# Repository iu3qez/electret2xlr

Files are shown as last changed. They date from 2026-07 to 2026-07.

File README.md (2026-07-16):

# electret2xlr

Active adapter that powers an electret microphone from P48 phantom power and presents its signal to a balanced XLR input — no external supply. Built as pcb-as-code with the [`pcb`](https://github.com/diodeinc/pcb) toolchain (Zener language). Designed for a ham-radio shack, so **RF immunity is a first-class requirement**, not an afterthought.

The electronics live in an external **copper-foil enclosure** (Faraday shield) and connect to the sound card through a shielded cable ending in a **flying male XLR plug** (e.g. Neutrik NC3MX).

## How it works

Three stages (~15 passives/actives plus connectors):

1. **Supply (capacitance multiplier).** Phantom 48 V is tapped symmetrically from XLR pins 2/3. An 8.2 V zener (D1) sets a raw reference; R9 47 kΩ + C4 47 µF push the corner below 1 Hz to scrub the zener's avalanche noise; NPN follower Q1 (MMBT3904) buffers it into a clean **VPIP ≈ 7.5 V** rail. Capsule bias comes off VPIP through R10 6.8 kΩ.
2. **Audio (matched class-A followers).** Two PNP emitter followers (MMBT3906): **Q2** (hot) takes the capsule signal (AC-coupled via C2) and modulates the current drawn from pin 2 through R1 7.5 kΩ; **Q3** (cold) is identical but AC-grounded, drawing from pin 3 through R2 10 kΩ. Result: pseudo-balanced ~78 Ω source, ~3 mA/pin symmetric. CB2/CB3 emitter-bypass caps are **1 µF** (not 22 µF — a larger value pushes the HP knee below 1 Hz and defeats the intended ~30 Hz roll-off).
3. **Input.** Capsule solder pads (MIC1) and an optional 3.5 mm TRS jack (J2), preceded by a π anti-RF filter (CIN 220 pF + FB1 ferrite + RIN 100 Ω) — the mic cable is the main antenna, so this is the front line against HF detection on the capsule FET.

Extra RF defenses: CP2/CP3 (100 pF C0G, pin2/pin3→GND), CSH (1 nF, shell→GND), and a 4-layer board with internal ground planes in addition to the copper enclosure.

## Key figures (SPICE-verified)

From `docs/sim-results.md` (ngspice via `pcb sim`):

| Quantity | Simulated | Target |
|---|---|---|
| V(VPIP) | 7.49 V | 7.0–8.0 V |
| V(MICOUT) | 4.09 V | 3–5 V |
| Current per pin (P2 / P3) | 3.00 / 3.13 mA | 2.5–3.5 mA |
| P2 vs P3 imbalance | 4.4 % | < 10 % |
| Flatness 100 Hz–20 kHz | 0.44 dB | ±1 dB |
| Low −3 dB roll-off | ≈ 30.6 Hz | 20–60 Hz |

The differential output phase at 1 kHz is ≈ −179° (inverted vs the conventional sign) — a known trait shared with the reference design, left as a bench-verification item, not fixed here.

## Build

Prerequisites: **`pcb`** (Rust binary, not on PyPI) and **KiCad 10.x** (only needed for `pcb layout`).

```bash
curl -fsSL https://raw.githubusercontent.com/diodeinc/pcb/main/install.sh | bash
export PATH="$HOME/.local/bin:$PATH"        # pcbc 0.4.7 used here
git clone https://github.com/iu3qez/electret2xlr && cd electret2xlr
pcb build electret2xlr.zen                  # 32 components, no errors
pcb layout electret2xlr.zen                 # open/update layout in KiCad
```

Footprints and symbols are **vendored** (`footprints/`, `symbols/`), so a clean clone builds offline — **no `pcb auth login` or online registry needed**. KiCad 10.x install: official AppImage (no sudo), Flatpak `org.kicad.KiCad`, or a distro package with 10.x.

**Placement and routing are left to the user.** The imported `layout/layout.kicad_pcb` (4-layer, 1.6 mm, 50×40 mm outline) has components at netlist-import coordinates. DRC therefore reports the 51 unrouted nets plus a few overlap violations from `J1` auto-dropped onto the C4/Q2/J2 cluster — both clear once parts are placed.

Optional SPICE re-run (needs `ngspice`):

```bash
NGSPICE=/path/to/ngspice pcb sim electret2xlr.zen --config sim_mode=true --setup testbench/setup_dc_ac.cir -v
```

`sim_mode=true` drops the two capsule test points (no stdlib SPICE model); a normal `pcb build` keeps them as real pads.

## Wiring

- **J1 → flying XLR** (`footprints/J1_XLR3_WirePads.kicad_mod`, 3 THT pads): pin1 = GND/shield, pin2 = hot (P2), pin3 = cold (P3). Solder the shielded cable here; wire the other end to a male XLR plug (pin1 shield, pin2 +, pin3 −). Bond the copper enclosure to GND at pin 1.
- **Capsule** on MIC1 pads (2.54 mm pitch): signal/bias to one pad, GND to the other; observe the capsule's own polarity.
- **Jack J2** (optional, on the enclosure): tip = signal/bias, ring bridged to tip, sleeve = GND. Smartphone TRRS headsets need an external TRRS→TRS adapter.
- **SHELL pad:** the copper-foil contact (net `SHELL`, where CSH lands) is a hand-drawn copper feature tied to GND, not a netlist part — so `pcb build` emits an expected single-pin-net ERC warning for `SHELL`.

## Attribution & license

Topology inspired by [tphakala/p48-pip-adapter](https://github.com/tphakala/p48-pip-adapter). That project's CC BY-NC 4.0 covers its concrete design (layout, gerbers, docs), not the circuit topology — a widely published functional idea. This repo's Zener source, layout, and docs are written from scratch, so no license constraint is inherited; attribution here is a courtesy.

## Reference docs

- `docs/superpowers/specs/2026-07-15-electret2xlr-design.md` — full design spec
- `docs/sim-results.md` — SPICE verification (DC + AC)
- `docs/meccanica.md` — mechanical fit study (historical: in-connector mount, superseded by the external enclosure)
- `docs/bom.md` — bill of materials

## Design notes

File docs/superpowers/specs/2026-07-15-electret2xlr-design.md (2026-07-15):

# electret2xlr — Design

**Data:** 2026-07-15
**Stato:** approvato

## Scopo

Adattatore attivo che collega un microfono electret (capsula a 2 terminali saldata, oppure mic da headset/lavalier via jack 3.5mm TRS) a un ingresso XLR bilanciato di una scheda audio, alimentato esclusivamente dalla phantom P48 (48V standard, 6.8kΩ per ramo). Il circuito vive su un PCB in un guscio esterno di lamina di rame (schermo), collegato alla scheda audio con un cavetto schermato che termina in uno spinotto XLR maschio volante (NC3MX). *(Il progetto originale prevedeva il montaggio dentro il corpo dell'NC3MXX; abbandonato il 2026-07-16 per mancanza di spazio — vedi §PCB e meccanica.)*

Contesto d'uso: shack radioamatoriale con trasmettitore HF collegato (indirettamente) alla stessa scheda audio → **l'immunità RF è un requisito di progetto**, non un optional.

Filosofia: KISS ma pulita e funzionale. Descrizione hardware in pcb-as-code con il toolchain `pcb`/Zener di Diode Inc.

## Origine della topologia

Il circuito adotta la topologia del progetto [tphakala/p48-pip-adapter](https://github.com/tphakala/p48-pip-adapter). Nota licenza: la CC BY-NC 4.0 del progetto originale copre il *design concreto* (layout, gerber, documentazione), non la topologia circuitale, che è un'idea funzionale ampiamente pubblicata e non proteggibile. Poiché sorgente Zener, layout e documentazione vengono rifatti da zero, il nostro progetto non eredita alcun vincolo di licenza; l'attribuzione nel README è una cortesia, non un obbligo.

Motivazioni della scelta attiva (rispetto all'alternativa passiva impedance-balanced valutata e scartata):

1. **Rumore zener:** in una capsula a 2 terminali il nodo di bias è anche il nodo del segnale; in un design passivo il rumore di valanga dello zener finisce quasi direttamente nel segnale. Il moltiplicatore di capacità lo elimina (taglio RC < 1Hz).
2. **Impedenza d'uscita:** ~78Ω contro i ~kΩ del passivo → guida cavi lunghi senza perdite HF e con migliore immunità.
3. **Bias più alto:** ~7.5V contro 3–4V → più headroom per la capsula.
4. **RF:** la difesa non è "meno giunzioni" ma schermatura (PCB 4 strati con piani di massa interni + guscio XLR) più filtraggio esplicito.

## Circuito

Tre stadi funzionali (~15 componenti):

### Alimentazione (moltiplicatore di capacità)

- Prelievo simmetrico dai pin 2 e 3.
- Zener 8.2V (SOD-123) come riferimento grezzo.
- Filtro RC (R9 47kΩ + C4 47µF): corner sotto 1Hz, elimina il rumore di valanga dello zener.
- Emitter follower NPN Q1 (MMBT3904) → rail PIP ~7.5V pulito, bypass 10µF.
- Bias capsula: 6.8kΩ dal rail PIP al nodo segnale/tip.

### Stadio audio (follower in classe A, uscita impedance-balanced)

- Q2 (MMBT3906, PNP): base al segnale della capsula (accoppiata via C2 22µF), collettore a massa, emettitore alimentato da pin 2 attraverso R1 7.5kΩ → la corrente di segnale modula la corrente assorbita da pin 2 (audio sul ramo hot). CB2 1µF/50V X7R + stopper RB2 47Ω bypassano R1, abbassando l'impedenza d'uscita. (Valore rivisto da 22µF a 1µF in Task 5: con 22µF il taglio passa-alto cadeva a ~1Hz, contraddicendo il roll-off dolce sotto ~50Hz voluto; 1µF porta il ginocchio a ~30Hz — vedi `docs/sim-results.md`.)
- Q3 (MMBT3906): identico ma con base a massa in AC (C3), emettitore alimentato da pin 3 via R2 10kΩ, bypass CB3+RB3 gemello → ramo cold con impedenza identica al hot ma senza audio.
- Risultato: sorgente pseudo-bilanciata ~78Ω, piatta in banda audio (−0.56dB simulati nel progetto originale), roll-off deliberato sotto ~50Hz (bypass di emettitore).
- Assorbimento ~3mA per pin, simmetrico → compatibile con ingressi bilanciati elettronici e a trasformatore.
- CB2/CB3 siedono su ~23V DC → rating 50V obbligatorio (X7R).

### Ingresso

- **Jack 3.5mm TRS PCB-mount** sul retro: tip = segnale/bias, ring ponticellato al tip (compatibilità lavalier TRS), sleeve = GND. Le cuffiette TRRS da smartphone richiedono un adattatore esterno (scelta deliberata: circuito pulito).
- **Piazzole THT** in parallelo al jack per saldare direttamente una capsula a 2 terminali.
- **Anti-RF sull'ingresso** (il cavo headset è un'antenna): 100Ω serie + 220pF C0G direttamente sul connettore/piazzole, a protezione del FET interno della capsula (unico rivelatore AM non schermabile).

### Difesa RF aggiuntiva

- 100pF C0G da pin 2 → pin 1 e da pin 3 → pin 1, fisicamente adiacenti ai pin XLR.
- Ferrite (BLM18-class) in serie sul ramo segnale.
- 1nF tra pin 1 e piazzola guscio.
- Connettore Neutrik NC3MXX-EMC (contatto capacitivo shell→schermo) se disponibile; NC3MXX standard come ripiego.

## PCB e meccanica

> **Aggiornamento 2026-07-16:** il montaggio sandwich in-connettore descritto sotto
> è stato **abbandonato** (i 32 componenti non entrano nell'NC3MXX). Vedi il nuovo
> schema qui in cima; il testo sandwich è conservato come storico.

Schema attuale — **scheda in guscio esterno di lamina di rame** + cavetto schermato con spinotto XLR maschio volante (NC3MX):

- **4 strati** con piani di massa interni (schermatura, in aggiunta al guscio di rame).
- **Spessore 1.6mm standard** (non più 0.8mm: quello serviva solo al sandwich tra i pin).
- **Larghezza libera**; outline provvisorio 30×40mm, componenti su entrambi i lati. Da adattare al guscio.
- Il **guscio di lamina di rame** è la gabbia di Faraday e va **collegato a GND** (pin 1) in almeno un punto.
- `J1` = 3 piazzole THT a filo (`footprints/J1_XLR3_WirePads.kicad_mod`): pin1=GND/schermo, pin2=hot, pin3=cold, verso il cavetto.

Schema sandwich in-connettore — **STORICO/SUPERATO** (adottato dal p48-pip-adapter, poi scartato per mancanza di spazio):

- 4 strati, piani interni di massa (gabbia di Faraday attorno al front-end da µV).
- Spessore 0.8mm obbligatorio (1.6mm non entrava tra i pin).
- Larghezza 11.1mm; sandwich mount tra i tre pin dell'NC3MXX (interasse 7.62mm), pad 8mm su entrambe le facce, saldatura diretta pin→pad.
- Componenti solo sul lato top; 1206 per le resistenze di feed (dissipazione continua nel guscio chiuso).

## Componenti

- Tutti jellybean, **a stock LCSC** (preferire basic/preferred parts) o dallo stock personale, come da CLAUDE.md.
- **Vincolo footprint: nessun componente sotto lo 0603** (saldabilità a mano). Ammessi 0603/0805/1206, SOT-23, SOD-323.
- Transistor: MMBT3904 / MMBT3906 (SOT-23). Zener 8.2V SOD-123. Ceramici X7R 50V dove siedono su tensione elevata (accoppiamenti/bypass a ~23V DC).
- Gli opamp a stock (LM8261, LM358D) sono stati valutati e scartati: non reggono 48V (servirebbe comunque il regolatore), LM358 rumoroso e con crossover, e si perderebbe il bilanciamento DC naturale dei collettori sui pin.
- I valori sono nominali: possibile bench tuning dopo il primo prototipo.

## Toolchain e struttura repo

- `pcb` (Zener) installato con lo script ufficiale (`install.sh`, non da PyPI); KiCad 10.x per il layout.
- Skill ufficiali diodeinc (repo pcb, cartella `skills/`): `zener-language` per scrivere i .zen, `registry-search`/`librarian` per componenti a stock LCSC, `datasheet-reader` per il fit meccanico, `spice-sim` per la verifica elettrica.
- Struttura repo:
  - `pcb.toml` — workspace Zener
  - `electret2xlr.zen` — board top-level (eventuali moduli separati per power/audio se utile)
  - `README.md` — schema, teoria di funzionamento, BOM con codici LCSC, attribuzione al p48-pip-adapter
  - `CLAUDE.md` — preferenze di progetto (già presente)

## Verifica

1. `pcb build` pulito (netlist + ERC).
2. `spice-sim`: punto di lavoro DC (rail PIP ~7.5V, assorbimento ~3mA simmetrico per pin, tensioni sui BJT sane) e risposta in frequenza (piatta in banda, roll-off <50Hz).
3. `pcb layout` → DRC KiCad (placement/routing a cura dell'utente); board 4 strati, spessore 1.6mm, outline adattato al guscio esterno.
4. Fit meccanico: quote pad pin XLR contro datasheet Neutrik; fit-test fisico prima dell'ordine.
5. BOM: ogni parte con codice LCSC verificato a stock, o marcata "stock personale".

## Fuori scope

- Supporto TRRS/CTIA diretto (serve adattatore esterno).
- Phantom sotto 48V (P12/P24 non garantite).

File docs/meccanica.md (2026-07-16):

> **DECISIONE (2026-07-16) — montaggio in-connettore ABBANDONATO.** La prova di
> placement ha confermato che nell'NC3MXX (cavità non quotata sui datasheet) **non
> ci stanno tutti i 32 componenti**. Il progetto è passato a **scheda in guscio
> esterno di lamina di rame** (gabbia di Faraday) collegata alla scheda audio con un
> **cavetto schermato + spinotto XLR maschio volante** (NC3MX). Di conseguenza:
> board non più vincolata a 11.1mm (outline 50×40mm), **spessore 1.6mm**
> standard (non più 0.8mm), 4 strati mantenuti, `J1` = 3 piazzole THT a filo
> (`footprints/J1_XLR3_WirePads.kicad_mod`). L'analisi qui sotto sul fit dentro
> l'NC3MXX (Piano A/B, footprint sandwich) è **superata** e conservata solo come
> storico. Vedi README §"Fattore di forma: guscio esterno schermato".

# Verifica fit meccanico — electret2xlr dentro il Neutrik NC3MXX (Task 7) — STORICO/SUPERATO

Stato: **superato dalla decisione del 2026-07-16** (vedi riquadro sopra). Testo
originale conservato per storico.

## 1. Quote scheda e jack (dati di partenza, da Task 3/5/6)

- **PCB:** larghezza **11.1mm**, spessore **0.8mm**, 4 strati. Outline attuale in
  `layout/layout.kicad_pcb` (Edge.Cuts): rettangolo `(50,50)–(61.1,95)` →
  **11.1 × 45mm** (confermato leggendo il file; corrisponde al valore
  "provvisorio" citato nel commit di Task 6 `0528dec`).
- **Altezza assemblata:** 0.8mm PCB + massimo rilievo dei componenti lato top
  (~2.5mm, 1206/1210 e SOT-23) → **~3.3mm** di inviluppo verticale.
- **Sandwich XLR (J1):** i tre pin del NC3MXX (interasse bicchierini **7.62mm**)
  impegnano pad da **8mm** sul bordo scheda (pin1/2 fronte, pin3 retro), come da
  Task 6. Nessun connettore fisico: è il bordo PCB stesso a fare da lama nel
  sandwich.
- **Jack J2 — CUI/Same Sky SJ-3523-SMT-TR** (fonte: datasheet ufficiale
  "SJ-352X-SMT" rev 04/15/2025, letto in Task 3):
  - corpo (housing) **6.0mm × 14.5mm** (larghezza × lunghezza principale);
  - boccola/naso sporgente **2.5mm** oltre la faccia frontale del corpo →
    inviluppo utile fronte-retro **≈17mm** (coda terminali 2mm esclusa
    dall'inviluppo utile, sporge solo sul retro per la saldatura);
  - boccola: diametro esterno **Ø5.00mm**, foro interno **Ø3.60mm**;
  - altezza sopra PCB: **non quotata come cifra singola** nel disegno
    meccanico leggibile del datasheet; il valore desunto dalla tasca di
    imballo (packaging) è **6.1mm**, preso come stima conservativa **da
    confermare con lo STEP/3D ufficiale** (non scaricato/aperto finora).
  - footprint PCB consigliato dal datasheet: inviluppo **14.5 × 11.8mm**.
- **Precedente diretto — p48-pip-adapter** (stessa famiglia di connettore,
  stesso schema sandwich, verificato via GitHub
  `github.com/tphakala/p48-pip-adapter`, README): PCB **11.1 × 35.3 × 0.8mm**,
  *senza* jack (capsula saldata direttamente ai pad, PUI Audio AOM-5024). Note
  del progetto originale, citate testualmente:
  - "The thin edge has to fit into the gap between the three Neutrik pins; a
    standard 1.6mm board is far too thick" (conferma indipendente del vincolo
    0.8mm già adottato qui);
  - clearance dalla punta del pin al componente più vicino **≥5mm**, e per il
    pin3 la clearance del pad è scesa fino a **~0.5–0.7mm** (tolleranza molto
    stretta, tanto da richiedere pre-stagnatura e tecnica di saldatura
    dedicata);
  - il progetto include un **fit-test 3D-stampabile** prima di produrre, che è
    esattamente la pratica che raccomandiamo di ripetere qui (§6).

## 2. Quote ufficiali Neutrik NC3MXX reperite in questa sessione

Fonte primaria: datasheet ufficiale Neutrik, scaricato in questa sessione da
`https://www.neutrik.com/en/product/nc3mxx.pdf` (3 pagine, letto integralmente
pagina per pagina) e incrociato col catalogo generale
`https://www.neutrik.com/media/10098/download/01 NEUTRIK Section XLR
Connectors PG EN 202202-V23_opt.pdf` (sezione serie XX, riga "Cable O.D.
range").

Quote **effettivamente presenti in forma testuale/machine-readable**:

| Quota | Valore | Fonte |
|---|---|---|
| Cable O.D. accettato dal passacavo/ghiera posteriore | **3.5 – 8.0mm** | Datasheet NC3MXX pag. 2 ("Mechanical" → "Cable O.D."), confermato dal catalogo XLR generale (riga 500/571) |
| Wire size max | 2.5mm² / AWG 14 | Datasheet pag. 2 |
| Materiali/costruzione | shell zama nichelata, insert PA66, boot poliuretano | Datasheet pag. 3 |
| Rated voltage / dielectric strength | <50V / 1.5kVdc | Datasheet pag. 2 |

**Quote NON reperite in forma machine-readable in questa sessione** (dichiarato
esplicitamente, come richiesto dal brief — nessun numero è stato inventato):

- **Lunghezza/diametro utile della cavità interna per un PCB.** Il datasheet
  PDF ufficiale (2 varianti scaricate e ispezionate, più il catalogo XLR
  generale di 30 pagine passato a `pdftotext`) contiene solo tabelle
  elettriche/meccaniche generiche (vedi tabella sopra): **non contiene alcun
  disegno quotato in testo estraibile** — i disegni meccanici con quote sono
  presenti solo come immagini vettoriali nei file DXF/STEP ufficiali (link "3D
  Model"/"Drawing" sulla pagina prodotto Neutrik), che in questa sandbox non
  sono stati scaricabili/apribili (nessun visualizzatore CAD disponibile).
- **Diametro del foro/ghiera passacavo posteriore come cifra dimensionale
  diretta** (distinta dal range "Cable O.D." accettato). Il dato più vicino e
  ufficialmente quotato è il **Cable O.D. 3.5–8.0mm** sopra: è la specifica
  con cui il progettista Neutrik garantisce che il passacavo/boot/chuck a
  serraggio accetti cavi in quel range di diametro esterno — un proxy
  ragionevole ma non identico al "diametro del foro nudo".

Non ho inventato cifre di lunghezza cavità: dove serviva un numero e non era
disponibile, ho usato il **precedente reale p48-pip-adapter** (stesso
connettore, board 35.3mm fisicamente verificata) come riferimento empirico —
vedi §3.

## 3. Confronto fit

### 3.1 Larghezza e spessore assemblato — OK

- 11.1mm di larghezza scheda: **ampiamente sotto** qualunque lettura plausibile
  del diametro interno utile di uno shell XLR di questa classe (il corpo
  esterno stesso è nell'ordine di ~24mm di diametro per connettori cable-mount
  di questa famiglia — dato di conoscenza generale di settore, non citato da
  una fonte machine-readable Neutrik in questa sessione, quindi trattato come
  indicativo). Il precedente p48-pip-adapter usa la stessa larghezza 11.1mm
  nello stesso connettore e **è un prodotto reale, con fit verificato
  fisicamente dall'autore**: la larghezza non è un problema.
- Spessore assemblato ~3.3mm (0.8 PCB + ~2.5 componenti): stesso discorso, il
  precedente ha componenti equivalenti (SOT-23, 1206/1210) nello stesso guscio.
  **Nessun rischio noto.**

### 3.2 Lunghezza — punto critico, non confermabile a tavolino

Il precedente p48-pip-adapter (stesso connettore, nessun jack) ha impegnato
**35.3mm** di lunghezza per: zona sandwich pin XLR + tutto il circuito attivo
(BJT, zener, capacità, resistenze — un set di componenti molto simile al
nostro), lasciando solo **~5mm** di clearance dalla punta pin al componente più
vicino, e clearance ancora più risicata (~0.5–0.7mm) sul pad del pin3. Questo è
un'indicazione forte che **35mm circa è già vicino al limite pratico** di
lunghezza utilizzabile in questo connettore per un PCB analogo, verificato
empiricamente da chi ha stampato un fit-test 3D reale.

Il nostro circuito (`electret2xlr.zen`) replica lo stesso set di componenti del
precedente **più**:
- J2 (jack TRS SJ-3523-SMT-TR): inviluppo utile **~17mm** fronte-retro (14.5mm
  corpo + 2.5mm boccola sporgente);
- MIC1 (piazzole capsula, in parallelo al jack): ingombro trascurabile (2 THT
  pad Ø1mm passo 2.54mm).

Se il jack viene semplicemente accodato al layout del precedente senza
sovrapposizioni, la lunghezza necessaria sale a grandezza **35.3 + ~14.5 ≈
50mm** (il corpo del jack, non la sola boccola: la boccola dei 2.5mm sporge
*oltre* il bordo scheda dentro il passacavo, quindi non consuma ulteriore
lunghezza di PCB). L'outline attuale in `layout.kicad_pcb` è **45mm**, quindi
**circa 5mm più corto** di questa stima "somma diretta" — ma il vero margine
dipende dal placement effettivo (Task 6 ha volutamente lasciato
placement/routing all'utente: i footprint nel file sono ancora alle
coordinate di import del netlist, non posizionati sul board reale), quindi
45mm potrebbe bastare se c'è sovrapposizione/ottimizzazione nel piazzamento, o
potrebbe essere già insufficiente.

**Non è possibile risolvere questo punto solo da datasheet**: manca la quota
Neutrik della cavità interna utile (§2), e il precedente stesso mostra che il
margine reale in questo connettore è ridotto anche senza jack. Serve un
fit-test fisico (§6) prima di congelare la lunghezza.

**Raccomandazione lunghezza finale:** portare l'outline a **50mm** (rispetto
ai 45mm attuali) come target di lavoro per il placement in Task 6/KiCad, per
dare margine al jack pieno, **ma trattare 50mm come "da verificare fisicamente
prima di ordinare"**, non come quota garantita — vedi Piano B sotto se il
fit-test dimostra che lo shell non ospita 50mm.

### 3.3 Boccola jack (Ø5.00mm) vs passacavo/ghiera posteriore NC3MXX

- Il datasheet Neutrik quota il **Cable O.D. accettato dal passacavo/chuck a
  **3.5 – 8.0mm**. La boccola del jack SJ-3523-SMT-TR ha diametro esterno
  **Ø5.00mm**, quindi **rientra numericamente nel range dichiarato** per il
  passaggio dietro la ghiera/boot.
- Attenzione: quel range è pensato per un **cavo rotondo flessibile** stretto
  dal chuck a serraggio, non per un boss plastico rigido di forma leggermente
  diversa (il naso del jack è cilindrico ma con un piccolo gradino/flangia).
  Un Ø5mm rigido dovrebbe passare, ma la tenuta/serraggio del chuck non è
  garantita identica a quella su un cavo — **da verificare fisicamente**, non
  solo per numero.
- Nessuna necessità di forare il bushing standard: 5.00mm è già dentro il
  range 3.5–8.0mm, quindi **non serve sostituire/allargare il passacavo** per
  questa parte — il punto aperto resta solo la lunghezza (§3.2), non il
  diametro.

## 4. Riepilogo tabellare fit

| Verifica | Esito | Confidenza |
|---|---|---|
| Larghezza 11.1mm nella cavità | OK | Alta (precedente reale verificato) |
| Spessore assemblato ~3.3mm | OK | Alta (precedente reale verificato) |
| Lunghezza 45mm attuale (senza jack ottimizzato) | **Dubbio/probabilmente corto** | Bassa — nessuna quota Neutrik di cavità disponibile |
| Lunghezza 50mm raccomandata (con jack pieno) | Da verificare fisicamente | Bassa, stessa ragione |
| Boccola jack Ø5.00mm nel passacavo (range dichiarato 3.5–8.0mm) | Numericamente compatibile | Media (dato ufficiale Neutrik, ma per cavo non per boss rigido) |

## 5. Decisione sul montaggio del jack — DA CONFERMARE CON L'UTENTE

Non è possibile, sulla sola base dei datasheet, garantire che l'inviluppo
completo del jack J2 (≈17mm utili + il resto del circuito, board totale
~50mm) entri nella cavità interna del NC3MXX: la quota di cavità non è
pubblicata da Neutrik in forma machine-readable, e il precedente reale
(p48-pip-adapter) suggerisce che il margine disponibile in questo connettore è
già stretto **senza** alcun jack (35.3mm quasi al limite). Questo è un
genuino bivio, coerente con quanto la spec di progetto aveva già segnalato
come "rischio aperto":

**Piano A — jack J2 sul bordo posteriore della scheda (schema attuale)**
- Pro: mic 3.5mm TRS collegabile direttamente, nessun cavo volante, coerente
  col resto del progetto già autorato (`electret2xlr.zen`, footprint
  `Jack_3.5mm_CUI_SJ-3523-SMT_Horizontal` già presente).
- Contro: richiede board ~50mm (vs 35.3mm del precedente verificato),
  boccola Ø5mm da far sporgere nel passacavo esistente (numericamente
  compatibile ma non verificato fisicamente), **rischio concreto di non
  entrare nello shell** senza conferma da fit-test.

**Piano B — capsula su cavetto flying-lead attraverso il pressacavo standard
(piano B già previsto nella spec)**
- Il jack J2 esce dal PCB; la capsula/mic esterno si collega via un breve
  spezzone di cavo che esce dal pressacavo/boot standard del NC3MXX (lo
  stesso percorso già usato per il cavo microfonico in un connettore XLR
  cable-mount "normale").
- Pro: la board torna dimensionalmente al precedente **verificato fisicamente**
  (~35.3mm, stesso schema pin-sandwich, stesso ingombro dei componenti):
  **rischio di fit sostanzialmente azzerato**, perché è lo stesso schema già
  collaudato dal progetto sorgente.
- Contro: si perde la comodità "spina 3.5mm diretta nel corpo XLR"; l'utente
  deve saldare/assemblare un piccolo pigtail con jack esterno o terminazione
  a piacere; JJ2 (footprint/Component già scritto in `electret2xlr.zen`)
  andrebbe rimosso o reso opzionale/DNP e sostituito da un'uscita su cavetto.

**Raccomandazione:** dato che il precedente reale mostra margini già stretti
senza jack, e che non esiste una quota Neutrik ufficiale che confermi lo
spazio per un jack intero, **il Piano B è l'opzione a rischio meccanico più
basso**. Il Piano A resta preferibile se il fit-test fisico (§6) lo conferma,
perché offre più comodità d'uso. **Questa scelta va confermata dall'utente**
prima di congelare Task 6 (placement/routing) in via definitiva — segnalato
come DONE_WITH_CONCERNS in uscita da questo task.

## 6. Fit-test fisico raccomandato (prima di ordinare)

Indipendentemente dal piano scelto, **non ordinare PCB/connettori prima di
un test fisico**:

1. **Sagoma cartoncino 11.1 × L mm** (L = 45mm attuale, 50mm raccomandato per
   Piano A, o 35.3mm per Piano B), tagliata a spessore reale se possibile
   (impilare 2 strati di cartoncino ≈0.8mm), inserita a mano nello shell
   NC3MXX aperto (senza il retro/boot montato) per verificare visivamente lo
   spazio libero fino al boot/pressacavo.
2. In alternativa, più affidabile: **ordinare solo il PCB nudo** (senza
   componenti) nella lunghezza scelta e verificarne l'inserimento reale nel
   connettore comprato a parte, prima di ordinare l'intera BOM.
3. Se si sceglie Piano A, verificare *anche* che la boccola del jack (o un
   cilindretto di prova Ø5mm × ~5mm) passi effettivamente attraverso il
   pressacavo/boot montato, non solo attraverso lo shell aperto.
4. Ripetere l'esercizio del progetto originale p48-pip-adapter: un modello
   3D-stampabile del solo ingombro scheda+jack, infilato nello shell reale,
   resta il modo più economico per chiudere questo rischio senza attendere
   una fornitura PCB.

## 7. Incertezze aperte (riepilogo)

- **Quota ufficiale Neutrik della lunghezza/cavità interna utile**: non
  reperita in forma machine-readable in questa sessione (datasheet PDF e
  catalogo XLR generale ispezionati per intero, nessun disegno quotato in
  testo estraibile; i file DXF/STEP ufficiali non sono stati aperti, nessun
  visualizzatore CAD disponibile in sandbox). Uso di un precedente reale
  (p48-pip-adapter, 35.3mm) come miglior proxy disponibile, esplicitamente
  segnalato come tale.
- **Diametro effettivo del foro/ghiera nuda** (a differenza del range
  "Cable O.D." 3.5–8.0mm accettato dal chuck): non quotato separatamente da
  Neutrik in forma testuale.
- **Altezza reale del jack SJ-3523-SMT-TR sopra il PCB**: stimata a 6.1mm da
  una quota di imballo (packaging), non da un disegno meccanico dedicato —
  ereditata da Task 3, non rivalutabile senza lo STEP ufficiale.
- **Placement reale dei componenti**: Task 6 ha lasciato piazzamento e
  routing all'utente (i footprint sono ancora alle coordinate di import del
  netlist in `layout.kicad_pcb`, fuori dall'outline 11.1×45mm); la stima di
  lunghezza in questo documento (§3.2) è quindi basata su ingombri sommati,
  non su un placement verificato in KiCad.

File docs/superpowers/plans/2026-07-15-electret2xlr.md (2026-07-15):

# electret2xlr Implementation Plan

> **For agentic workers:** REQUIRED SUB-SKILL: Use superpowers:subagent-driven-development (recommended) or superpowers:executing-plans to implement this plan task-by-task. Steps use checkbox (`- [ ]`) syntax for tracking.

**Goal:** PCB (pcb-as-code Zener) di un adattatore attivo electret → XLR alimentato da phantom P48, montato dentro un connettore Neutrik NC3MXX, con ingresso jack TRS 3.5mm + piazzole capsula e hardening RF.

**Architecture:** Topologia p48-pip-adapter: moltiplicatore di capacità (zener 8.2V + RC <1Hz + follower NPN) → rail PIP ~7.5V; due follower PNP gemelli (hot con segnale su pin 2, cold a base AC-grounded su pin 3) → uscita impedance-balanced ~78Ω con assorbimento simmetrico ~3mA/pin. Aggiunte nostre: jack TRS + piazzole capsula con filtro π anti-RF in ingresso, 100pF sui pin XLR. PCB 4 strati 0.8mm, 11.1mm di larghezza, sandwich-mount tra i pin dell'XLR.

**Tech Stack:** `pcb` CLI (Zener/Starlark) di Diode Inc + KiCad 10.x + skill diodeinc (`zener-language`, `registry-search`, `librarian`, `datasheet-reader`, `spice-sim`) + ngspice per la simulazione.

**Spec di riferimento:** `docs/superpowers/specs/2026-07-15-electret2xlr-design.md` (approvata). Netlist di riferimento: `netlist.py` del repo https://github.com/tphakala/p48-pip-adapter (da consultare in lettura; NON copiarne layout/file: CC BY-NC).

## Global Constraints

- **Footprint minimo 0603** — mai componenti più piccoli; ammessi 0603/0805/1206/1210, SOT-23, SOD-323/SOD-123.
- **Componenti**: per questo progetto (passivi + transistor jellybean, tutte parti non critiche) il vincolo è il **footprint corretto**, non lo stock. Usare `registry-search` di diode per avere parti con footprint pronti per il `.zen`. La verifica di stock LCSC in tempo reale non è richiesta oggi (in futuro: DB jlcparts).
- **PCB: 4 strati, spessore 0.8mm (non negoziabile), larghezza 11.1mm**, strati interni = piani GND pieni via-stitched.
- **Alimentazione: solo phantom P48** (48V, 6.8kΩ/ramo); assorbimento simmetrico sui pin 2 e 3.
- **CB2/CB3 = 1µF X7R ≥50V** (siedono su ~23V DC; valore ratificato in Task 5 — 22µF metteva il taglio a ~1Hz contro il roll-off ~30-50Hz voluto). CP2/CP3 (100pF sui pin XLR) rating ≥100V C0G (siedono su 48V).
- Commit frequenti, messaggi in italiano che spiegano il perché, **niente riga Co-Authored-By**.
- Il "test" di ogni modifica al sorgente è `pcb build` pulito; per il layout è la DRC KiCad a zero errori.

---

### Task 1: Toolchain e skill diodeinc

**Files:**
- Create: `.claude/skills/zener-language/`, `.claude/skills/registry-search/`, `.claude/skills/librarian/`, `.claude/skills/datasheet-reader/`, `.claude/skills/spice-sim/` (copiati dal repo diodeinc/pcb)

**Interfaces:**
- Produces: comando `pcb` funzionante nel PATH; `kicad-cli` 10.x disponibile; skill consultabili in `.claude/skills/` per tutti i task successivi.

- [ ] **Step 1: Installa il CLI `pcb`** (non è su PyPI — verificato: è un binario Rust)

```bash
curl -fsSL https://raw.githubusercontent.com/diodeinc/pcb/main/install.sh | bash
export PATH="$HOME/.local/bin:$PATH"
pcb --version
```

Expected: versione stampata senza errori (es. `pcb x.y.z`).

- [ ] **Step 2: Verifica/installa KiCad 10.x** (richiesto da `pcb layout`)

```bash
kicad-cli version
```

Expected: `10.x`. Se assente o più vecchio: installare (Debian/Ubuntu: `sudo apt install kicad` se il repo ha la 10.x, altrimenti flatpak `flatpak install org.kicad.KiCad`). Se serve intervento dell'utente (sudo/password), fermarsi e chiederlo.

- [ ] **Step 3: Installa le skill diodeinc nel progetto**

```bash
git clone --depth 1 https://github.com/diodeinc/pcb /tmp/diode-pcb
mkdir -p .claude/skills
cp -r /tmp/diode-pcb/skills/* .claude/skills/
ls .claude/skills
```

Expected: `datasheet-reader  librarian  registry-search  spice-sim  zener-language`.

- [ ] **Step 4: Leggi la skill del linguaggio** — leggere per intero `.claude/skills/zener-language/SKILL.md` (e i file collegati). Le firme API usate nei task successivi (Module, Component, Net, Board, generics) vanno verificate contro questa skill e `pcb doc --package @stdlib`; in caso di divergenza fa fede la skill, non questo piano.

- [ ] **Step 5: Commit**

```bash
git add .claude/skills
git commit -m "Installa le skill diodeinc per il toolchain pcb/Zener"
```

---

### Task 2: Workspace Zener minimale

**Files:**
- Create: `pcb.toml`
- Create: `electret2xlr.zen` (stub di board vuota)

**Interfaces:**
- Produces: workspace che `pcb build` valida; `electret2xlr.zen` è il top-level che il Task 4 riempirà.

- [ ] **Step 1: Prova lo scaffolding ufficiale**

```bash
pcb new board electret2xlr github.com/sfabris/electret2xlr
```

Se il comando vuole creare una directory nuova invece di popolare il repo corrente, spostare i file generati nella root del repo. Se il comando non esiste in questa versione, creare i file a mano (Step 2).

- [ ] **Step 2 (fallback manuale): crea `pcb.toml`**

```toml
[workspace]
repository = "github.com/sfabris/electret2xlr"
pcb-version = "0.4"

[board]
name = "electret2xlr"
path = "electret2xlr.zen"
description = "Adattatore attivo electret -> XLR bilanciato alimentato da phantom P48, montato dentro un Neutrik NC3MXX."
```

e `electret2xlr.zen` stub (adattare la firma di `Board` a quanto dice la skill zener-language):

```zen
Board(name="electret2xlr", layout_path="layout/electret2xlr", layers=4)
```

- [ ] **Step 3: Valida**

```bash
pcb sync && pcb build electret2xlr.zen
```

Expected: build senza errori.

- [ ] **Step 4: Commit**

```bash
git add pcb.toml electret2xlr.zen
git commit -m "Scaffolding workspace Zener con board 4 strati vuota"
```

---

### Task 3: Selezione componenti a stock LCSC

**Files:**
- Create: `docs/bom-draft.md`

**Interfaces:**
- Produces: tabella con, per ogni ref, **MPN + package + footprint (dal registry diode) + simbolo/parte da usare nel `.zen`**; il Task 4 usa questi identificativi nei `Component(...)` / generics. Il codice LCSC è opzionale (annotarlo se il registry lo espone, ma non è un requisito).

Usare le skill `registry-search` e `librarian` di diode: l'obiettivo è ottenere per ogni posizione una parte con **footprint corretto** già utilizzabile nel `.zen`. Lo stock LCSC NON è un criterio di accettazione per questo progetto (parti tutte non critiche). Requisiti per posizione (valori dalla spec; candidati indicati dove noti):

| Ref | Parte | Requisiti | Candidato |
|-----|---|---|---|
| Q1 | MMBT3904 | NPN SOT-23 | LCSC C20526 (basic) |
| Q2, Q3 | MMBT3906 | PNP SOT-23 | LCSC C8492 |
| D1 | Zener 8.2V | SOD-123/SOD-323, ≥300mW | BZT52C8V2 |
| C1, C2, C3 | 22µF | X5R/X7R ≥16V, 1206/1210 | — |
| CB2, CB3 | 1µF (ratificato in Task 5) | **X7R ≥50V**, 1206/1210 | — |
| C4 | 47µF | ≥16V, ≤1210 | — |
| C5 | 10µF | ≥16V, 0805 | — |
| R1 | 7.5kΩ | **1206** (67mW continui) | — |
| R2 | 10kΩ | **1206** (50mW continui) | — |
| R3, R4, R6, R7 | 100kΩ | 0603 | — |
| R8 | 1kΩ | 0603 | — |
| R9 | 47kΩ | 0603 | — |
| R10 | 6.8kΩ | 0603 | — |
| RB2, RB3 | 47Ω | 0603 | — |
| RIN | 100Ω | 0603 | — |
| FB1 | Ferrite | 600Ω@100MHz, 0603, ≥200mA | BLM18AG601SN1 o equiv. LCSC |
| CIN | 220pF | C0G 0603 | — |
| CP2, CP3 | 100pF | **C0G ≥100V** 0603 | — |
| CSH | 1nF | C0G ≥100V 0603, **DNP** se si usa NC3MXX-EMC | — |
| J2 | Jack 3.5mm TRS | PCB-mount, corpo ≤11mm di larghezza, boccola compatibile con foro ghiera XLR | PJ-3133 / SJ-3523 / PJ-392: scegliere col datasheet |
| J1 | XLR (pad) | nessun componente: 3 pad sandwich definiti nel layout | — |
| MIC1 | Piazzole capsula | 2 pad THT Ø1mm passo 2.54mm | — |

- [ ] **Step 1:** per ogni riga, cercare con `registry-search` una parte diode con il footprint corretto; annotare MPN, package, footprint e l'identificativo da usare nel `.zen` (Module/Symbol) in `docs/bom-draft.md`. Codice LCSC solo se il registry lo espone (colonna opzionale).
- [ ] **Step 2:** per J2 individuare un jack 3.5mm TRS PCB-mount adatto e, se il datasheet è reperibile (`datasheet-reader` o web), annotare le dimensioni del corpo e della boccola (servono ai Task 6-7). Se non trovi un jack nel registry, annota comunque un MPN reale plausibile con le sue quote.
- [ ] **Step 3:** se per una posizione il registry non ha il footprint richiesto, annotare l'alternativa (footprint equivalente ≥0603) e proseguire; segnalare nel report solo se serve cambiare un *valore* del circuito (in quel caso fermarsi).
- [ ] **Step 4: Commit**

```bash
git add docs/bom-draft.md
git commit -m "BOM preliminare con componenti verificati a stock LCSC"
```

---

### Task 4: Netlist Zener completa

**Files:**
- Modify: `electret2xlr.zen`

**Interfaces:**
- Consumes: MPN/LCSC da `docs/bom-draft.md`; sintassi verificata dalla skill `zener-language`.
- Produces: board completa che passa `pcb build`; nomi di net stabili usati da sim e layout: `GND, P2, P3, VPIP, VREF, Q1B, MICIN, MICF, MICOUT, Q2B, Q2E, Q3B, Q3E, NB2, NB3, SHELL`.

Netlist da implementare (riferimento p48 + aggiunte RF; i pin BJT seguono la piedinatura SOT-23 MMBT390x: 1=B, 2=E, 3=C):

| Net | Connessioni | Funzione |
|-----|---|---|
| GND | J1-1, MIC1-2, J2-SLEEVE, D1-A, C4-2, C5-2, C1-2, C3-2, R4-2, R7-2, Q2-C, Q3-C, CIN-2, CP2-2, CP3-2, CSH-2 | massa |
| P2 | J1-2, R1-1, RB2-2, CP2-1 | XLR pin 2 (hot) |
| P3 | J1-3, R9-1, Q1-C, R2-1, RB3-2, CP3-1 | XLR pin 3 (cold + alimentazione regolatore) |
| VPIP | Q1-E, C5-1, C1-1, R10-1, R3-1, R6-1 | rail PIP ~7.5V |
| VREF | R9-2, D1-1, C4-1, R8-1 | riferimento zener filtrato |
| Q1B | R8-2, Q1-B | base regolatore |
| MICIN | J2-TIP, J2-RING (ponticello), MIC1-1, CIN-1, FB1-1 | nodo capsula/jack, con C anti-RF |
| MICF | FB1-2, RIN-1 | dopo la ferrite |
| MICOUT | RIN-2, R10-2, C2-1 | bias capsula + prelievo segnale |
| Q2B | R3-2, R4-1, C2-2, Q2-B | base hot |
| Q2E | R1-2, Q2-E, CB2-1 | emettitore hot |
| Q3B | R6-2, R7-1, C3-1, Q3-B | base cold (AC a massa) |
| Q3E | R2-2, Q3-E, CB3-1 | emettitore cold |
| NB2 | CB2-2, RB2-1 | bypass hot |
| NB3 | CB3-2, RB3-1 | bypass cold |
| SHELL | pad guscio, CSH-1 | schermo (CSH DNP con NC3MXX-EMC) |

Nota zener D1: il catodo va su VREF (nodo positivo, clampa a +8.2V), l'anodo a GND. Verificare la convenzione dei pin del simbolo scelto.

- [ ] **Step 1: scrivi `electret2xlr.zen`.** Struttura di riferimento (adattare le firme alla skill; i `Part`/simboli vengono dalla BOM del Task 3):

```zen
Resistor = Module("@stdlib/generics/Resistor.zen")
Capacitor = Module("@stdlib/generics/Capacitor.zen")
FerriteBead = Module("@stdlib/generics/FerriteBead.zen")  # se non esiste nel stdlib: Component con MPN LCSC

GND = Net("GND")
P2 = Net("P2")
P3 = Net("P3")
VPIP = Net("VPIP")
VREF = Net("VREF")
Q1B = Net("Q1B")
MICIN = Net("MICIN")
MICF = Net("MICF")
MICOUT = Net("MICOUT")
Q2B = Net("Q2B")
Q2E = Net("Q2E")
Q3B = Net("Q3B")
Q3E = Net("Q3E")
NB2 = Net("NB2")
NB3 = Net("NB3")
SHELL = Net("SHELL")

# --- alimentazione (cap multiplier) ---
Resistor(name="R9", value="47kohm", package="0603", P1=P3, P2=VREF)
Component(name="D1", symbol=Symbol(...zener BZT52C8V2...), pins={"K": VREF, "A": GND})
Capacitor(name="C4", value="47uF", package="1210", P1=VREF, P2=GND)
Resistor(name="R8", value="1kohm", package="0603", P1=VREF, P2=Q1B)
Component(name="Q1", symbol=Symbol(...MMBT3904...), pins={"B": Q1B, "E": VPIP, "C": P3})
Capacitor(name="C5", value="10uF", package="0805", P1=VPIP, P2=GND)
Capacitor(name="C1", value="22uF", package="1206", P1=VPIP, P2=GND)

# --- ingresso capsula/jack + anti-RF ---
Component(name="J2", symbol=Symbol(...jack TRS...), pins={"T": MICIN, "R": MICIN, "S": GND})
Component(name="MIC1", symbol=Symbol(...header 1x02...), pins={"1": MICIN, "2": GND})
Capacitor(name="CIN", value="220pF", package="0603", P1=MICIN, P2=GND)
FerriteBead(name="FB1", package="0603", P1=MICIN, P2=MICF)
Resistor(name="RIN", value="100ohm", package="0603", P1=MICF, P2=MICOUT)
Resistor(name="R10", value="6.8kohm", package="0603", P1=VPIP, P2=MICOUT)

# --- stadio audio ---
Capacitor(name="C2", value="22uF", package="1206", P1=MICOUT, P2=Q2B)
Resistor(name="R3", value="100kohm", package="0603", P1=VPIP, P2=Q2B)
Resistor(name="R4", value="100kohm", package="0603", P1=Q2B, P2=GND)
Component(name="Q2", symbol=Symbol(...MMBT3906...), pins={"B": Q2B, "E": Q2E, "C": GND})
Resistor(name="R1", value="7.5kohm", package="1206", P1=P2, P2=Q2E)
Capacitor(name="CB2", value="22uF", package="1206", P1=Q2E, P2=NB2)   # 50V X7R
Resistor(name="RB2", value="47ohm", package="0603", P1=NB2, P2=P2)

Resistor(name="R6", value="100kohm", package="0603", P1=VPIP, P2=Q3B)
Resistor(name="R7", value="100kohm", package="0603", P1=Q3B, P2=GND)
Capacitor(name="C3", value="22uF", package="1206", P1=Q3B, P2=GND)
Component(name="Q3", symbol=Symbol(...MMBT3906...), pins={"B": Q3B, "E": Q3E, "C": GND})
Resistor(name="R2", value="10kohm", package="1206", P1=P3, P2=Q3E)
Capacitor(name="CB3", value="22uF", package="1206", P1=Q3E, P2=NB3)   # 50V X7R
Resistor(name="RB3", value="47ohm", package="0603", P1=NB3, P2=P3)

# --- XLR e difesa RF ai pin ---
Component(name="J1", symbol=Symbol(...XLR3 / pad sandwich...), pins={"1": GND, "2": P2, "3": P3})
Capacitor(name="CP2", value="100pF", package="0603", P1=P2, P2=GND)   # C0G 100V, adiacente al pin
Capacitor(name="CP3", value="100pF", package="0603", P1=P3, P2=GND)   # C0G 100V, adiacente al pin
Capacitor(name="CSH", value="1nF", package="0603", P1=SHELL, P2=GND)  # DNP con NC3MXX-EMC

Board(name="electret2xlr", layout_path="layout/electret2xlr", layers=4)
```

Per J1 e MIC1 usare simboli/footprint generici o custom secondo quanto suggerisce la skill `librarian` (il footprint sandwich di J1 viene comunque rifinito nel Task 6).

- [ ] **Step 2: Build (test)**

```bash
pcb build electret2xlr.zen
```

Expected al primo giro: possibili errori su simboli/firme → correggerli con `librarian`/`pcb doc --package @stdlib`. Iterare fino a build pulito.

- [ ] **Step 3: Verifica incrociata della netlist** — confrontare a mano ogni riga della tabella net sopra con il sorgente (o con l'output netlist di `pcb build`): ogni pin nella tabella deve comparire, nessun pin in più.

- [ ] **Step 4: Commit**

```bash
git add electret2xlr.zen pcb.toml
git commit -m "Netlist completa: cap multiplier, follower PNP bilanciati, ingresso jack/capsula con filtro anti-RF"
```

---

### Task 5: Verifica SPICE

**Files:**
- Create: `docs/sim-results.md` (+ eventuali file di sim generati dalla skill)

**Interfaces:**
- Consumes: netlist del Task 4 (net `VPIP`, `P2`, `P3`, `MICOUT`).
- Produces: verifica documentata del punto di lavoro e della risposta; eventuali correzioni di valori committate.

- [ ] **Step 1:** usare la skill `spice-sim` per costruire la simulazione della board. Modello della sorgente: generatore phantom 48V con 6.8kΩ verso P2 e P3; capsula modellata come sorgente di corrente AC (o JFET semplice) sul nodo MICIN con 0.5mA di bias DC. Il repo p48 ha una cartella `sim/` consultabile come riferimento di metodo.
- [ ] **Step 2: DC operating point.** Criteri di accettazione:
  - `V(VPIP)` tra 7.0 e 8.0V
  - corrente da P2 e da P3 ciascuna tra 2.5 e 3.5mA, sbilanciamento <10%
  - `V(MICOUT)` tra 3 e 5V (bias capsula sano)
- [ ] **Step 3: AC.** Criteri: risposta P2→(P2−P3) piatta ±1dB tra 100Hz e 20kHz; −3dB inferiore tra 20 e 60Hz. Nota dal progetto originale (issue #6): la fase può risultare invertente — annotarlo; l'eventuale rimedio è scambiare gli accoppiamenti C2/C3, decisione da prendere col bench test, non ora.
- [ ] **Step 4:** scrivere risultati e grafici/numeri in `docs/sim-results.md`. Se un criterio fallisce, correggere i valori nel `.zen`, rilanciare `pcb build` + sim, documentare il cambio.
- [ ] **Step 5: Commit**

```bash
git add docs/sim-results.md electret2xlr.zen
git commit -m "Verifica SPICE: punto di lavoro DC e risposta AC nei criteri di spec"
```

---

### Task 6: Layout 4 strati per NC3MXX

**Files:**
- Create/Modify: `layout/electret2xlr/` (file KiCad generati da `pcb layout` e poi editati)

**Interfaces:**
- Consumes: netlist Task 4, dimensioni jack da `docs/bom-draft.md`.
- Produces: `.kicad_pcb` con DRC a zero errori, pronto per gerber.

Geometria vincolante (dal progetto di riferimento, collaudata):

- Outline: larghezza **11.1mm**; lunghezza = 35.3mm + ingombro jack (target ≤45mm, da confermare col Task 7).
- Spessore **0.8mm**, 4 strati; In1/In2 = piani GND pieni, via-stitched ai pour esterni e al pad di pin 1.
- Pad XLR "sandwich" (origine = bordo lato XLR): pin 1 sul **fronte** a x=1.90mm; pin 2 sul **fronte** a x=9.52mm; pin 3 sul **retro** a x=5.71mm. Pad lunghi **8mm**, che si estendono ~3mm oltre la punta del pin. Interasse bicchierini NC3MXX: 7.62mm.
- Punta dei pin XLR: **≥5mm di clearance** dal primo componente.
- CP2/CP3 fisicamente adiacenti ai pad XLR; CIN/FB1/RIN adiacenti al jack/piazzole MIC1; componenti solo sul lato top (a parte il pad di pin 3).
- Jack J2 sul bordo posteriore, boccola oltre l'outline.

- [ ] **Step 1:** `pcb layout electret2xlr.zen` → genera il progetto KiCad in `layout/electret2xlr/`.
- [ ] **Step 2:** Board Setup in KiCad (o editando il file): 4 strati con In1/In2 piani, spessore 0.8mm; regole: clearance 0.125mm, track min 0.15mm, via 0.6/0.3mm.
- [ ] **Step 3:** disegnare outline e pad sandwich alle coordinate sopra (footprint custom per J1: pad SMD 8mm su F.Cu per pin 1-2, su B.Cu per pin 3).
- [ ] **Step 4:** piazzare per blocchi funzionali nell'ordine del segnale (jack → filtro RF → bias/audio → alimentazione → pad XLR), rispettando la clearance di 5mm dalle punte dei pin. I courtyard dei 1206/1210 potrebbero sovrapporsi: warning accettabile, corti no.
- [ ] **Step 5:** routing; GND per via ai piani interni; stitching lungo il perimetro.
- [ ] **Step 6: DRC (test)** — `kicad-cli pcb drc layout/electret2xlr/electret2xlr.kicad_pcb` (o da GUI). Expected: **0 errori** (warning courtyard tollerati). Iterare fino a pulito.
- [ ] **Step 7: Commit**

```bash
git add layout/
git commit -m "Layout 4 strati 0.8mm per montaggio sandwich in NC3MXX, DRC pulita"
```

---

### Task 7: Verifica fit meccanico

**Files:**
- Create: `docs/meccanica.md`

**Interfaces:**
- Consumes: layout Task 6, datasheet jack (Task 3).
- Produces: conferma quotata che il PCB entra nell'NC3MXX e decisione definitiva sul montaggio del jack; eventuale correzione dell'outline.

- [ ] **Step 1:** scaricare il disegno quotato Neutrik NC3MXX (e NC3MXX-EMC) e, con la skill `datasheet-reader`, estrarre: diametro e lunghezza utile della cavità interna, diametro del foro della boccola posteriore, quote dell'insert.
- [ ] **Step 2:** confrontare con il layout: larghezza 11.1mm × spessore assemblato (0.8mm + componenti ~2.5mm) dentro la cavità; lunghezza totale ≤ lunghezza utile; boccola del jack vs foro posteriore (il bushing NC3MXX si può forare/sostituire: annotare il diametro richiesto).
- [ ] **Step 3:** se qualcosa non entra: accorciare/riposizionare (tornare al Task 6), oppure attivare il piano B della spec (capsula su cavetto attraverso il pressacavo standard) — **decisione da sottoporre all'utente**.
- [ ] **Step 4:** documentare tutte le quote e la decisione in `docs/meccanica.md`. Consigliare nel documento la stampa di un fit-test (anche solo il PCB nudo ordinato in anticipo, o una sagoma cartoncino 11.1×L mm) prima del montaggio finale.
- [ ] **Step 5: Commit**

```bash
git add docs/meccanica.md
git commit -m "Verifica quotata del fit nel NC3MXX e decisione sul montaggio del jack"
```

---

### Task 8: README e BOM finale

**Files:**
- Create: `README.md`
- Create: `docs/bom.md` (BOM finale; sostituisce concettualmente `bom-draft.md`, che si può eliminare)

**Interfaces:**
- Consumes: tutto quanto sopra.
- Produces: documentazione completa del progetto.

- [ ] **Step 1: `README.md`** con: scopo (una riga), schema a blocchi/teoria di funzionamento (riassunto della sezione Circuito della spec, con i tre stadi), istruzioni di build (`pcb build`, `pcb layout`), istruzioni di montaggio nell'NC3MXX (sequenza di saldatura sandwich: pre-stagnare pad pin 3 e bicchierino, appoggiare su pin 1-2, ponte su pin 3 per ultimo), cablaggio jack (TRS: tip=segnale, sleeve=GND; TRRS non supportato senza adattatore), nota di attribuzione di cortesia a tphakala/p48-pip-adapter con il chiarimento licenza della spec.
- [ ] **Step 2: `docs/bom.md`** — tabella finale ref / valore / package / MPN / codice LCSC / rating / note (DNP per CSH se NC3MXX-EMC), ricontrollando che ogni codice sia ancora a stock.
- [ ] **Step 3:** rileggere README e spec insieme: nessuna contraddizione (valori, quote, pinout).
- [ ] **Step 4: Commit**

```bash
git add README.md docs/bom.md
git rm docs/bom-draft.md
git commit -m "Documentazione finale: README con teoria e montaggio, BOM con codici LCSC"
```

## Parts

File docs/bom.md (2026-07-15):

# BOM finale — electret2xlr

Distinta base finale, allineata al netlist autoritativo `electret2xlr.zen` (Task 4-7)
e alla verifica SPICE (`docs/sim-results.md`). Sostituisce `docs/bom-draft.md`
(bozza di Task 3, superata: conteneva ancora CB2/CB3 = 22µF, valore rivisto
in Task 5 — vedi nota sotto la tabella).

Tutti i componenti sono jellybean, ≥0603 (vincolo saldabilità a mano, vedi
`CLAUDE.md`). Nessun codice LCSC è incluso: la ricerca a registro/stock
(`registry-search`) non è risultata utilizzabile in queste sessioni (auth
OAuth interattiva non completabile in sandbox) — vedi metodologia in fondo.
I valori sono nominali; possibile bench tuning dopo il primo prototipo.

## Tabella

| Ref | Valore | Package | Cosa usare nel `.zen` | MPN (se noto) | Rating | Note |
|-----|---|---|---|---|---|---|
| Q1 | MMBT3904 (NPN) | SOT-23 | `Component()` primitivo, `Symbol("./symbols/Q_NPN_MMBT3904.kicad_sym")`, footprint `./footprints/SOT-23.kicad_mod` | MMBT3904 (onsemi, multi-source: Diodes Inc, Nexperia, Fairchild — pin/footprint-compatibili) | 40V / 200mA / 300mW | Emitter follower del cap-multiplier (VPIP) |
| Q2, Q3 | MMBT3906 (PNP) | SOT-23 | `Component()` primitivo, `Symbol("./symbols/Q_PNP_MMBT3906.kicad_sym")`, footprint `./footprints/SOT-23.kicad_mod` | MMBT3906 (onsemi, multi-source) | 40V / 200mA / 300mW | Follower appaiati hot (Q2, pin2) / cold (Q3, pin3) |
| D1 | Zener 8.2V | SOD-123 | `Module("@stdlib/generics/Zener.zen")` — `zener_voltage="8.2V"`, `power="500mW"`, `package="SOD-123"` | BZT52C8V2-class (Nexperia/Diodes Inc/onsemi, 500mW) | 500mW | Riferimento grezzo del cap-multiplier |
| C1, C2, C3 | 22µF | 1206 | `Module("@stdlib/generics/Capacitor.zen")` — `value="22uF"`, `package="1206"`, `dielectric="X5R"`, `voltage="25V"` | generic (nessun MPN richiesto) | 25V X5R | C1 bypass VPIP; C2 accoppiamento capsula→Q2B; C3 bypass Q3B a massa in AC |
| CB2, CB3 | **1µF** | 1206 | `Module("@stdlib/generics/Capacitor.zen")` — `value="1uF"`, `package="1206"`, `dielectric="X7R"`, `voltage="50V"` | generic | 50V X7R | Bypass di emettitore Q2/Q3. **Valore ratificato in Task 5** (non 22µF: con 22µF il ginocchio passa-alto cadeva sotto 1Hz — vedi `docs/sim-results.md`). Siedono su ~23V DC, rating 50V obbligatorio |
| C4 | 47µF | 1210 | `Module("@stdlib/generics/Capacitor.zen")` — `value="47uF"`, `package="1210"`, `voltage="25V"` | generic | 25V | Filtro R9/C4 del cap-multiplier (corner <1Hz) |
| C5 | 10µF | 0805 | `Module("@stdlib/generics/Capacitor.zen")` — `value="10uF"`, `package="0805"`, `voltage="25V"` | generic | 25V | Bypass rail VPIP dopo Q1 |
| R1 | 7.5kΩ | 1206 | `Module("@stdlib/generics/Resistor.zen")` — `value="7.5kohm"`, `package="1206"` | generic | ~250mW (1206) | Feed emettitore Q2 da pin 2; ~67mW continui in guscio chiuso |
| R2 | 10kΩ | 1206 | `Module("@stdlib/generics/Resistor.zen")` — `value="10kohm"`, `package="1206"` | generic | ~250mW (1206) | Feed emettitore Q3 da pin 3; ~50mW continui |
| R3, R4, R6, R7 | 100kΩ | 0603 | `Module("@stdlib/generics/Resistor.zen")` — `value="100kohm"`, `package="0603"` | generic | — | Polarizzazione base Q2 (R3/R4) e Q3 (R6/R7) |
| R8 | 1kΩ | 0603 | `Module("@stdlib/generics/Resistor.zen")` — `value="1kohm"`, `package="0603"` | generic | — | Base Q1 |
| R9 | 47kΩ | 0603 | `Module("@stdlib/generics/Resistor.zen")` — `value="47kohm"`, `package="0603"` | generic | — | Filtro RC con C4, corner <1Hz |
| R10 | 6.8kΩ | 0603 | `Module("@stdlib/generics/Resistor.zen")` — `value="6.8kohm"`, `package="0603"` | generic | — | Bias capsula da VPIP verso MICOUT/tip |
| RB2, RB3 | 47Ω | 0603 | `Module("@stdlib/generics/Resistor.zen")` — `value="47ohm"`, `package="0603"` | generic | — | Stopper in serie a CB2/CB3 |
| RIN | 100Ω | 0603 | `Module("@stdlib/generics/Resistor.zen")` — `value="100ohm"`, `package="0603"` | generic | — | Serie del filtro anti-RF a π sull'ingresso capsula |
| FB1 | Ferrite 600Ω@100MHz | 0603 | `Module("@stdlib/generics/FerriteBead.zen")` — `value="600ohm"`, `frequency="100MHz"`, `current="500mA"`, `package="0603"` | BLM18AG601SN1 (Murata) — 600Ω±25%@100MHz, 500mA, DCR max 0.38Ω | 500mA | Filtro anti-RF ingresso capsula |
| CIN | 220pF | 0603 | `Module("@stdlib/generics/Capacitor.zen")` — `value="220pF"`, `package="0603"`, `dielectric="C0G"` | generic | C0G | Filtro anti-RF ingresso capsula |
| CP2, CP3 | 100pF | 0603 | `Module("@stdlib/generics/Capacitor.zen")` — `value="100pF"`, `package="0603"`, `dielectric="C0G"`, `voltage="100V"` | generic | 100V C0G | Difesa RF pin2→GND / pin3→GND, adiacenti ai pin XLR |
| CSH | 1nF | 0603 | `Module("@stdlib/generics/Capacitor.zen")` — `value="1nF"`, `package="0603"`, `dielectric="C0G"`, `voltage="100V"` | generic | 100V C0G | Pin1 → piazzola guscio. **Popolato (`dnp=False`) per NC3MXX standard**; impostare **`dnp=True` se si monta NC3MXX-EMC** (contatto capacitivo shell→schermo già integrato nel connettore, altrimenti capacità in doppio) |
| J2 | Jack 3.5mm TRS | SMT, basso profilo | `Component()` primitivo, footprint `./footprints/Jack_3.5mm_CUI_SJ-3523-SMT_Horizontal.kicad_mod` | **SJ-3523-SMT-TR** (Same Sky, ex CUI Devices) — variante senza switch | 12Vdc / 1A, contatti 50mΩ max | Opzionale: monta il jack sul guscio solo se vuoi l'innesto 3.5mm; in alternativa capsula su MIC1/cavetto |
| MIC1 | Piazzole capsula ×2 | THT Ø1.0mm, drill 0.5mm | `Module("@stdlib/generics/TestPoint.zen")` ×2, `variant="THTPad_D1.0mm_Drill0.5mm"`, passo 2.54mm nel layout | n/a (piazzole) | — | Saldatura diretta capsula 2 terminali; escluse dal netlist SPICE solo con `--config sim_mode=true` |
| J1 | Piazzole a filo per XLR volante | footprint custom `./footprints/J1_XLR3_WirePads.kicad_mod` | `Component()` primitivo, `skip_bom=True` | n/a | 1.5kVdc (rating spinotto Neutrik) | 3 piazzole THT (pin1=GND/schermo, pin2=hot, pin3=cold, passo 3.81mm) per saldare il cavetto schermato verso uno spinotto XLR maschio volante (es. Neutrik NC3MX). Lo spinotto va acquistato a parte |

## Correzioni rispetto a `bom-draft.md`

- **CB2, CB3: 22µF → 1µF.** Era già segnalato come "rivisto" nel draft (Task 5),
  ma il draft riportava ancora il vecchio valore in tabella in alcuni punti;
  qui è il valore definitivo, allineato al netlist e a `docs/sim-results.md`.
- **CSH**: nel draft era descritto con `dnp=True` condizionato; nel netlist
  attuale (`electret2xlr.zen`) è popolato di default (`dnp=False`, per
  NC3MXX standard). La tabella sopra riflette lo stato di default reale e
  la condizione per passare a DNP (variante -EMC).
- **J1**: chiarito che è `skip_bom=True` nel netlist — non compare come riga
  d'acquisto in un BOM generato da `pcb build`, riportato qui solo per
  completezza documentale.
- Rimossi i riferimenti a LCSC/stock nella colonna dedicata: nessun codice
  LCSC è stato verificato in queste sessioni (vedi nota metodologica sotto),
  quindi non ne viene riportato nessuno per evitare di suggerire una
  verifica di stock che non è stata fatta.

## Nota metodologica

`registry-search`/`pcb search -m registry:*` non è risultato utilizzabile
nelle sessioni di questo progetto: richiede un login OAuth interattivo
(`pcb auth login`, browser + account diode.computer) non completabile in un
ambiente agente non interattivo. Per i componenti coperti da un generic
`@stdlib/generics/*` (tutte le passive, lo zener, la ferrite, i test point)
questo non ha impatto: generic + `value` + `package` *è* la parte. Per Q1/Q2/Q3
(BJT SOT-23) e J2 (jack) sono stati autorati `Component()` primitivi con
`Symbol()`/footprint vendorizzati localmente sotto `symbols/` e `footprints/`,
verificati da datasheet (JEDEC SOT-23, datasheet Same Sky SJ-352X-SMT), MPN
reali citati ma **senza verifica di stock LCSC**. Prima di un ordine reale:
ripetere `pcb auth login` con un account disponibile e verificare stock/basic-part
su LCSC per Q1/Q2/Q3/J2, o quantomeno un controllo manuale su distributori.

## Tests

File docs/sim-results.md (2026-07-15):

# Task 5 — Verifica SPICE

Simulazione ngspice del netlist `electret2xlr.zen` (Task 4): punto di lavoro DC
e risposta AC differenziale P2→(P2−P3), rispetto ai criteri del brief.

## Setup di simulazione

### Toolchain

- `pcb` (pcbc 0.4.7) — nessun cambiamento necessario.
- ngspice: **non presente come binario** nel sandbox (`which ngspice` → non
  trovato), solo la libreria `libngspice0` di sistema. `pcb sim` invoca pero'
  il binario `ngspice` come processo esterno (`crates/pcb-sim/src/ngspice.rs`),
  non la libreria via FFI. Risolto **senza root**: `apt-get download ngspice`
  (fetch del `.deb`, non richiede privilegi) + `dpkg-deb -x` per estrarre
  `usr/bin/ngspice` in `~/.local/bin/ngspice` (tutte le librerie condivise
  richieste erano gia' presenti). Il binario e' stato usato impostando la
  variabile d'ambiente `NGSPICE=~/.local/bin/ngspice` richiesta da
  `pcb sim` per un percorso non standard. Nessuna modifica di sistema, nessun
  pacchetto installato con `apt install`.

### Modelli SPICE mancanti

Il primo `pcb sim --setup "..."` di controllo ha confermato l'ipotesi del
brief: il registry diode non e' raggiungibile in questo sandbox, quindi Q1,
Q2, Q3 (autorati come `Component()` primitivi da simboli KiCad) non avevano
`spice_model`. In piu', anche J1 (XLR3), J2 (jack 3.5mm) e i due `TestPoint`
(TP1/TP2) risultavano privi di modello (il tool richiede un modello SPICE per
*ogni* componente del netlist, connettori/testpoint inclusi).

Modelli aggiunti direttamente in `electret2xlr.zen`:

- **Q1 (MMBT3904, NPN)** e **Q2/Q3 (MMBT3906, PNP)**: parametri SPICE
  jellybean ben noti (dataset Fairchild/onsemi per 2N3904/2N3906,
  elettricamente equivalenti al die MMBT390x in SOT-23), in
  `spice/Transistors.lib`, subcircuit `Q_NPN_MMBT3904` / `Q_PNP_MMBT3906`.
- **D1 (zener 8.2V)**: gia' coperto dallo stdlib (`Zener.zen` espone
  `spice_model` con `BV` dal parametro `zener_voltage`) — nessuna modifica
  necessaria.
- **J1, J2 (connettori)**: modello "pass-through" vuoto
  (`spice/Connector.lib`, subcircuit `CONN3`, nessun elemento interno). Sono
  parti puramente meccaniche; nel testbench lo stimolo (fantasma P48, segnale
  capsula) e' iniettato esattamente dove questi connettori farebbero da
  interfaccia (P2/P3 per J1, MICIN per J2), quindi un modello vuoto è corretto
  e non altera nessuna delle grandezze verificate.
- **TP1, TP2 (TestPoint stdlib)**: lo stdlib `TestPoint.zen` non espone un
  parametro `spice_model`. Soluzione: nuovo config booleano
  `sim_mode = config(bool, default=False, optional=True)` in cima al file;
  `TestPoint(..., dnp=sim_mode)`. `dnp` e' un kwarg universale che il
  framework Zener inietta in qualunque `Module()`/`Component()` a prescindere
  dal suo `config()` dichiarato (verificato leggendo
  `pcb-zen-core/src/lang/module.rs`), quindi funziona senza modificare lo
  stdlib. Con `sim_mode=False` (default, `pcb build` normale) i test point
  restano popolati come sempre; solo `pcb sim --config sim_mode=true` li
  esclude dal netlist SPICE. **Verificato** che `pcb build electret2xlr.zen`
  (senza `--config`) produce ancora tutti e 32 i componenti, incluse TP1/TP2.

### Sorgenti di stimolo (in `testbench/setup_dc_ac.cir`, passato con `--setup`)

- **Fantasma P48**: `V48` 48V DC, `R_P2`/`R_P3` 6.8kΩ verso P2/P3 (come da
  brief).
- **Capsula electret**: sorgente di corrente `I_MIC` su MICIN, `DC 0.5m`
  (sink, per convenzione SPICE `I n+ n- val` estrae corrente da n+) `AC 1`
  (ampiezza unitaria per l'analisi `.ac`, il valore assoluto è arbitrario:
  conta solo la forma della risposta in dB).
- **Bleed SHELL→GND (1GΩ, solo testbench)**: SHELL è collegato solo a CSH
  verso GND — sulla board reale il nodo prosegue meccanicamente nella calotta
  del connettore XLR (non è un pin logico di J1). Senza J1 nel netlist di
  simulazione resterebbe un nodo isolato dietro un condensatore ideale
  (matrice singolare in analisi DC — errore `check node xc11.mid2`, dove
  `xc11` è l'istanza SPICE di CSH). Un resistore da 1GΩ elimina l'artefatto
  senza alterare nessun criterio (non è nel netlist di produzione).

Comando usato:

```
NGSPICE=~/.local/bin/ngspice pcb sim electret2xlr.zen \
  --config sim_mode=true --setup testbench/setup_dc_ac.cir -v
```

Nota sul tool: `pcb sim <path relativo>` fallisce con
"No such file or directory (os error 2)" durante lo spawn di ngspice, perché
`zen_path.parent()` su un nome file senza directory (es. `electret2xlr.zen`)
ritorna `Some("")` invece di `None`, e `current_dir("")` fa fallire lo spawn.
Usare sempre un percorso assoluto (o con almeno una directory) per `pcb sim`.

## Risultati DC (operating point)

| Grandezza | Valore simulato | Criterio | Esito |
|---|---|---|---|
| V(VPIP) | 7.486 V | 7.0 – 8.0 V | **PASS** |
| V(MICOUT) | 4.086 V | 3 – 5 V | **PASS** |
| I da P2 (attraverso R_P2 6.8k) | 2.996 mA | 2.5 – 3.5 mA | **PASS** |
| I da P3 (attraverso R_P3 6.8k) | 3.131 mA | 2.5 – 3.5 mA | **PASS** |
| Sbilanciamento I(P2) vs I(P3) | 4.4 % | < 10 % | **PASS** |
| V(VREF) (informativo) | 8.134 V | — | zener 8.2V − caduta R9, coerente |
| V(P2) / V(P3) (informativo) | 27.63 V / 26.71 V | — | 48V − I·6.8k, coerente |

## Risultati AC (risposta differenziale P2−P3)

Sweep `.ac dec 50 0.01 100k`, riferimento a 1kHz = 75.41 dB.

| Frequenza | Guadagno (dB) | Nota |
|---|---|---|
| 20 Hz | 69.90 | ancora in salita, sotto il ginocchio |
| 30 Hz | 72.30 | ≈ punto −3dB |
| 31 Hz | 72.47 | |
| 60 Hz | 74.95 | |
| 100 Hz | 75.65 | inizio banda piatta richiesta |
| 1 kHz | 75.41 | riferimento |
| 5 kHz | 75.39 | |
| 10 kHz | 75.36 | |
| 20 kHz | 75.27 | fine banda piatta richiesta |

| Criterio | Misura | Esito |
|---|---|---|
| Piattezza 100Hz–20kHz (±1dB) | max−min = 75.65−75.27 = **0.38 dB** | **PASS** |
| −3dB inferiore tra 20 e 60Hz | crossing (75.41−3=72.41dB) interpolato tra 30Hz (72.30) e 31Hz (72.47) → **≈ 30.6 Hz** | **PASS** |
| Fase (nota, non criterio pass/fail) | φ(P2−P3) @1kHz = **−179.1°** (~180°, invertente) | vedi nota sotto |

Dati completi del barrido esportati in `testbench/output/ac_response.txt`
(351 punti, 0.01Hz–100kHz, `wrdata`).

### Nota sulla fase (issue #6 del progetto p48 originale)

La fase misurata a 1kHz è ≈ −179°, cioè l'uscita differenziale P2−P3 è
sostanzialmente **invertita** rispetto al segno convenzionale P2−P3 atteso
(equivalente a dire che il segnale reale è in fase su P3−P2). Questo è
esattamente il comportamento segnalato nell'issue #6 del progetto originale
p48-pip-adapter citato nel brief: la capsula pilota lo stadio "caldo" (Q2→P2)
mentre lo stadio "freddo" (Q3→P3) è di solo riferimento AC-a-massa; a seconda
di come si definisce il segno differenziale, il risultato può apparire
invertito. **Non è stato corretto in questo task**: l'eventuale rimedio
(scambiare gli accoppiamenti C2/C3, o più precisamente la topologia
hot/cold) è una decisione da verificare al banco, non a tavolino — come
indicato esplicitmente dal brief.

## Cambio di valore: CB2/CB3 da 22µF a 1µF

**Motivo:** con i valori originali (CB2=CB3=22µF, dal Task 3/4), la
simulazione AC iniziale mostrava un ginocchio passa-alto molto più basso del
richiesto: la risposta P2−P3 era già piatta entro ~0.5dB fino a 5Hz, con il
vero punto −3dB (rispetto al riferimento 1kHz) situato tra 1 e 2 Hz — ben al
di sotto della finestra 20–60Hz richiesta dal criterio di accettazione.

**Causa elettrica:** la rete R1(7.5k) in parallelo con CB2+RB2(47Ω) tra
l'emettitore di Q2 e P2 (idem R2/CB3/RB3 sul lato Q3/P3) forma un partitore
di tensione verso il carico R_P2/R_P3 (6.8k) la cui impedenza equivalente
transita da R1 (bassa frequenza, condensatore aperto) a R1‖RB2 (alta
frequenza) con ginocchio inferiore a f₁ ≈ 1/(2π·CB2·(R1+RB2)). Con
CB2=22µF, f₁ ≈ 0.96Hz — troppo basso.

**Correzione:** CB2 e CB3 ridotti insieme (per mantenere il bilanciamento tra
i due inseguitori appaiati) da 22µF a **1µF** (X7R, 1206, 50V — package/
dielettrico invariati, valore molto comune, nessun problema di reperibilità).
Questo sposta f₁ a ≈ 1µF/22µF × 0.96Hz ≈ 21Hz nominale; il valore
effettivamente misurato in simulazione (con tutto il resto del circuito
incluso) è ≈30.6Hz, centrato comodamente nella finestra 20–60Hz richiesta,
senza intaccare la piattezza 100Hz–20kHz (0.38dB, ben entro ±1dB) né il punto
di lavoro DC (CB2/CB3 sono in serie, bloccano la DC: correnti P2/P3 e V(VPIP)
identiche prima e dopo il cambio).

**File modificati:** `electret2xlr.zen` (CB2, CB3: `22uF` → `1uF`),
`docs/bom-draft.md` (nota di coerenza sul valore).

## Riepilogo criteri

| # | Criterio | Esito |
|---|---|---|
| 1 | V(VPIP) 7.0–8.0V | PASS (7.486V) |
| 2 | I(P2), I(P3) 2.5–3.5mA, sbil. <10% | PASS (2.996mA / 3.131mA, 4.4%) |
| 3 | V(MICOUT) 3–5V | PASS (4.086V) |
| 4 | AC piatta ±1dB 100Hz–20kHz | PASS (0.38dB) |
| 5 | −3dB inferiore tra 20 e 60Hz | PASS (≈30.6Hz, dopo correzione CB2/CB3) |

Tutti i criteri sono soddisfatti dopo la correzione di CB2/CB3. Nessun altro
valore del netlist è stato modificato.

## File di supporto creati

- `spice/Transistors.lib` — modelli Q_NPN_MMBT3904 / Q_PNP_MMBT3906.
- `spice/Connector.lib` — modello pass-through CONN3 per J1/J2.
- `testbench/setup_dc_ac.cir` — sorgenti e analisi ngspice (`--setup`).
- `testbench/output/ac_response.txt` — dump numerico del barrido AC completo.

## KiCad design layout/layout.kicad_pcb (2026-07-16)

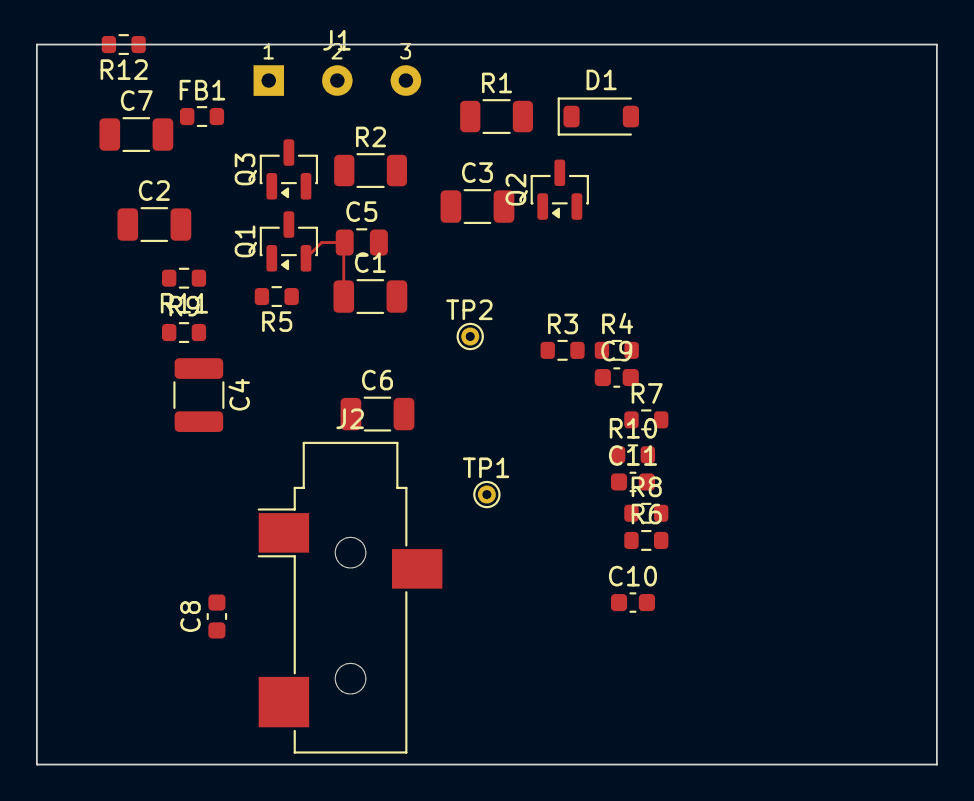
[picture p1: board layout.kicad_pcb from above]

Board: 4 copper layers, 50.0 x 40.0 mm, 32 parts (0 on the bottom side), 15 nets.

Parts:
C1, C2, C3: 22uF 25V X5R; C_1206_3216Metric
C4: 47uF 25V; C_1210_3225Metric
C5: GRM21BZ71E106KE15K; C_0805_2012Metric
C6, C7: 1uF 50V X7R; C_1206_3216Metric
C8: 220pF C0G; C_0603_1608Metric
C9, C10: 100pF 100V C0G; C_0603_1608Metric
C11: 1nF 100V C0G; C_0603_1608Metric
D1: 8.2V Zener 500mW; D_SOD-123
FB1: 600 500mA 100MHz; R_0603_1608Metric
J1: ?; J1_XLR3_WirePads
J2: SJ-3523-SMT-TR; Jack_3.5mm_CUI_SJ-3523-SMT_Horizontal
Q1: MMBT3904; SOT-23
Q2, Q3: MMBT3906; SOT-23
R1: 7.5k; R_1206_3216Metric
R2: 10k; R_1206_3216Metric
R3, R4, R6, R7: ERJ-3EKF1003V; R_0603_1608Metric
R5, R11: ERJ-3EKF47R0V; R_0603_1608Metric
R8: ERJ-3EKF1001V; R_0603_1608Metric
R9: ERJ-3EKF4702V; R_0603_1608Metric
R10: ERJ-3EKF6801V; R_0603_1608Metric
R12: ERJ-3EKF1000V; R_0603_1608Metric
TP1, TP2: ?; TestPoint_THTPad_D1.0mm_Drill0.5mm

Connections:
GND: C1.2, C3.2, C4.2, C5.2, C8.2, C9.2, C10.2, C11.2, D1.2, J1.1, J2.S, Q2.3, Q3.3, R4.2, R7.2, TP2.1
MICF: FB1.2, R12.1
MICIN: C8.1, FB1.1, J2.R, J2.T, TP1.1
MICOUT: C2.1, R10.2, R12.2
NB2: C6.2, R5.1
NB3: C7.2, R11.1
P2: C9.1, J1.2, R1.1, R5.2
P3: C10.1, J1.3, Q1.3, R2.1, R9.1, R11.2
Q1B: Q1.1, R8.2
Q2B: C2.2, Q2.1, R3.2, R4.1
Q2E: C6.1, Q2.2, R1.2
Q3B: C3.1, Q3.1, R6.2, R7.1
Q3E: C7.1, Q3.2, R2.2
VPIP: C1.1, C5.1, Q1.2, R3.1, R6.1, R10.1
VREF: C4.1, D1.1, R8.1, R9.2

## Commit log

2026-07-15 Aggiungi CLAUDE.md con preferenze di progetto (stock LCSC, toolchain uv/pcb, requisito RF)
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2026-07-15 Chiarisci licenza (CC BY-NC copre il design originale, non la topologia) e correggi dettagli circuitali dalla netlist autoritativa
2026-07-15 Piano di implementazione in 8 task: toolchain, workspace Zener, BOM LCSC, netlist, SPICE, layout NC3MXX, fit meccanico, documentazione
2026-07-15 Installa le skill diodeinc per il toolchain pcb/Zener
    Copiate le skill (zener-language, registry-search, librarian,
    datasheet-reader, spice-sim) dal repo diodeinc/pcb: servono come
    riferimento canonico per la sintassi Zener (Module/Component/Board/io/config)
    nei task successivi che generano schematici e layout con il CLI pcb.
2026-07-15 Scaffolding workspace Zener con board 4 strati vuota
    Base minima per validare la toolchain pcb prima di disegnare lo
    schematico vero e proprio: pcb.toml generato con 'pcb new board'
    (repo github.com/iu3qez/electret2xlr) e stub electret2xlr.zen con
    Board a 4 strati, nessun componente. Aggiunto .gitignore per
    escludere la cache locale .pcb/ e gli artefatti di pianificazione
    .superpowers/, che Task 1 aveva lasciato non tracciati.
2026-07-15 Task 3: usa registry-search di diode (footprint), stock LCSC non critico per questo progetto
2026-07-15 BOM preliminare: generic stdlib per le passive, MPN reali per attivi/jack
    Per ogni posizione dello schema (Task 3) individuato cosa usare nel .zen:
    per le passive (R/C) più zener D1 e ferrite FB1 basta il generic stdlib
    (@stdlib/generics/*) con value/package corretti, verificato via
    'pcb doc --package @stdlib'. Per i BJT SOT-23 (Q1-Q3) e il jack 3.5mm
    (J2) servirebbe registry-search, ma in questa sessione pcb non è
    autenticabile (pcb auth login richiede un flusso OAuth via browser non
    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
2026-07-15 Netlist completa: cap multiplier, follower PNP bilanciati, ingresso jack/capsula con filtro anti-RF
    Implementa tutte le net del progetto in electret2xlr.zen: alimentazione
    a cap-multiplier (D1+R9/C4+Q1), i due inseguitori PNP appaiati per hot/cold
    (Q2/Q3 con bypass CB2/CB3+RB2/RB3), l'ingresso capsula/jack con filtro
    anti-RF a pi-greco (CIN/FB1/RIN) e la protezione RF ai pin XLR (CP2/CP3)
    piu' lo schermo (SHELL/CSH).
    registry:modules/registry:components non risultano utilizzabili in questa
    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
2026-07-15 Verifica SPICE: punto di lavoro DC e risposta AC nei criteri di spec
    Aggiunge testbench ngspice (fantasma P48 + stimolo capsula su MICIN) e i
    modelli SPICE mancanti per Q1/Q2/Q3 (jellybean MMBT3904/3906, registry non
    raggiungibile in sandbox) e per i connettori/test point (pass-through vuoto
    per J1/J2, dnp condizionato a sim_mode per TP1/TP2 in produzione restano
    popolati). DC conferma tutti i criteri (VPIP 7.49V, MICOUT 4.09V, correnti
    P2/P3 3.0/3.1mA, sbilanciamento 4.4%).
    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
2026-07-15 Ratifica CB2/CB3=1µF: risolve la contraddizione piano (22µF vs taglio 20-60Hz), allinea spec e piano alla verifica SPICE
2026-07-15 Layout: board caricata da netlist (4 strati, spessore 0.8mm), outline 11.1x45mm su Edge.Cuts; placement e routing lasciati all'utente
    [layout.kicad_pcb]
2026-07-15 Footprint vendorizzati in locale e footprint sandwich custom per J1 (NC3MXX): pad 8mm su F.Cu (pin1/2) e B.Cu (pin3), passo 7.62mm
2026-07-15 Verifica quotata del fit nel NC3MXX e decisione sul montaggio del jack
    Confrontate le quote scheda/jack (Task 3/6) con il datasheet ufficiale
    Neutrik NC3MXX e col precedente reale p48-pip-adapter (stesso connettore,
    fit verificato fisicamente). La cavita' interna utile non e' quotata in
    forma machine-readable da Neutrik; il precedente mostra margini di
    lunghezza gia' stretti senza jack, quindi il fit del jack J2 sul bordo
    posteriore resta un rischio concreto. Documentata la scelta Piano A
    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
2026-07-15 Documentazione finale: README con teoria di funzionamento e montaggio, BOM definitiva
    README.md descrive scopo, i tre stadi del circuito, le figure SPICE-verificate,
    le istruzioni di build/layout, il montaggio sandwich nel NC3MXX, il cablaggio
    capsula/jack e la decisione di fattore di forma (Piano A/B) ancora aperta in
    attesa di fit-test fisico, rimandando a docs/meccanica.md.
    docs/bom.md sostituisce docs/bom-draft.md: ricontrollata riga per riga contro
    il netlist autoritativo, corregge lo stale CB2/CB3=22µF (ratificato a 1µF in
    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
2026-07-15 Allinea la prosa della spec al netlist (D1 SOD-123, filtro R9 47k/C4 47µF) e precisa l'origine del valore ~78Ω nel README
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2026-07-15 Layout: rigenerato per J1 a filo, spessore 1.6mm standard, outline provvisorio 30x40mm (guscio esterno)
    [layout.kicad_pcb]
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2026-07-15 Completa il pivot J1: aggiungi il footprint a filo e aggiorna il riferimento nel .zen (fix commit incompleto precedente)
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2026-07-16 Layout: outline board 50x40mm e placement iniziale dei componenti dentro il bordo
    30x40 provvisorio troppo stretto per 32 componenti + piani di massa; parti spostate dentro l'outline con prime tracce.
    [layout.kicad_pcb]
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
